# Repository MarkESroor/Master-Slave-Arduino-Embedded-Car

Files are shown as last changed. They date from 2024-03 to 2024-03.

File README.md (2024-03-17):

# Master Slave Arduino Embedded Car
 
The main idea is to implement a micro-controller based carwith multiple safety and entertainment features,
and apply the scheduling techniques that raise the safety level to a maximum.
It includes an autonomous lane departure system to avoid sway while moving and
keeping the driving path to avoid collision; it corrects the path with the right speed
while alerting the driver. In addition, the current gear of the car is displayed and can
be changed using a joystick. Moreover, adaptive headlights safety is not just limited
to the driver but to those around him as well. The headlights are adjusted
according to the brightness surrounding the car, meaning that at night the
headlights will work with enough intensity to show the road but not high enough to
obstruct the vision of other drivers. Finally, the sound system, user can play any
mp3 file through the touchscreen. The mp3 file name will be displayed and the user
can Play/Pause and iterate between the saved mp3 files.

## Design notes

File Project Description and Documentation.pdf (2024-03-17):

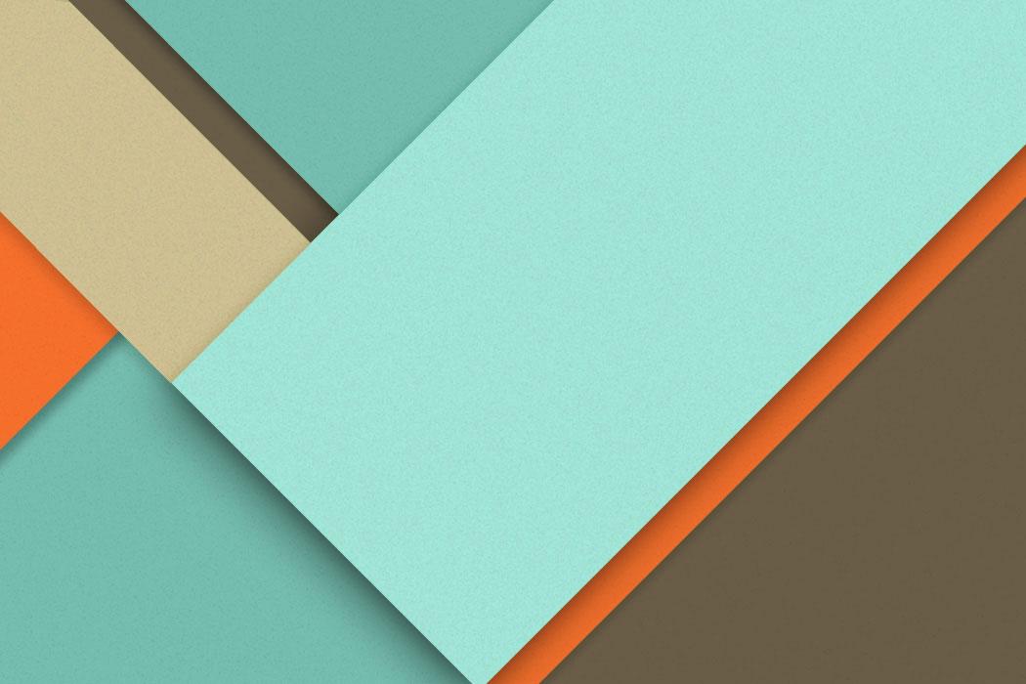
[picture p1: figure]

# Team 17

Name | ID | Tutorial Group
Mark Sroor | 46-5861 | T-22
Lougina Hatem | 46-13014 | T-22
Dareen Mohamed | 46-0416 | T-18
Omar Galal | 46-1097 | T-12

## Project Idea

The main idea is to implement a micro-controller based car with multiple safety and entertainment features .
and apply the scheduling techniques that raise the safety level to a maximum ,
It includes an autonomous lane departure system to avoid sway while moving and keeping the driving path to avoid collision; it corrects the path with the right speed while alerting the driver. In addition, the current gear of the car is displayed and can be changed using a joystick. Moreover, adaptive headlights safety is not just limited to the driver but to those around him as well. The headlights are adjusted according to the brightness surrounding the car, meaning that at night the headlights will work with enough intensity to show the road but not high enough to obstruct the vision of other drivers. Finally, the sound system, user can play any mp3 file through the touchscreen. The mp3 file name will be displayed and the user can Play/Pause and iterate between the saved mp3 files.

## Approach

First we worked on getting every component to be functional separately. Then we combined them together. After that we combined both arduinos and integrated everything.

C

i

r

c

u

i

t

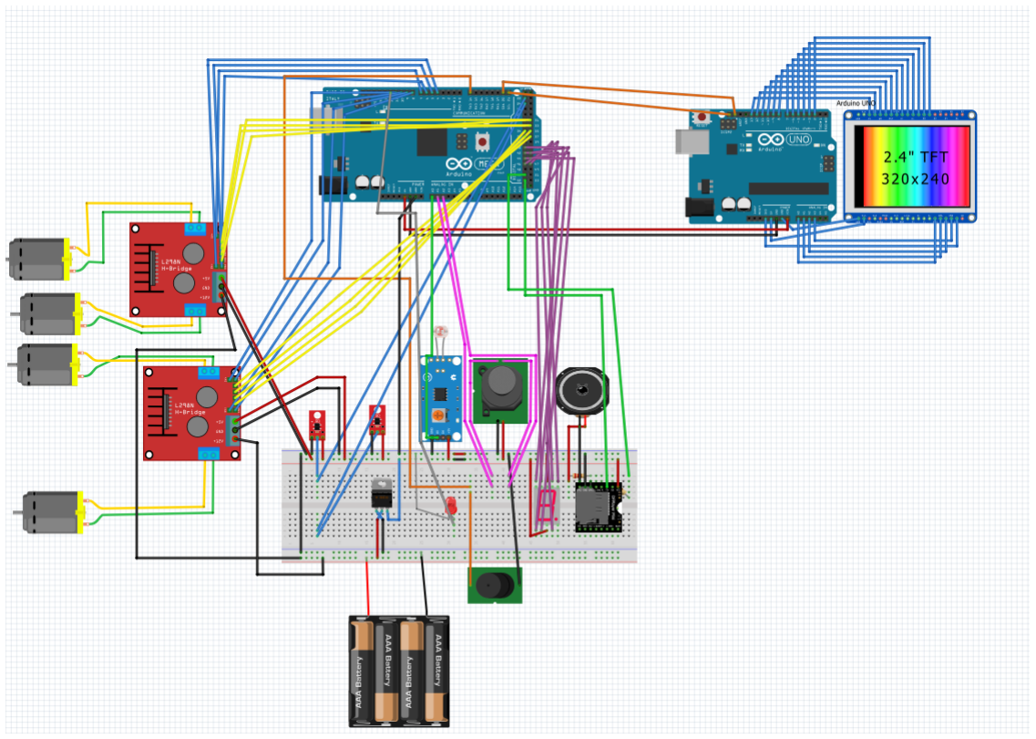
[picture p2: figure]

# Handling Inputs:

Regarding our inputs, they were from our sensors like our light detection sensor, lane detection sensor. These sensors were connected to the pwm ports of our arduino as we needed from analog to digital.

# Handling Outputs:

Regarding our outputs, they were from our sensors like our light detection sensor, lane detection sensor. These sensors were connected to the pwm ports of our arduino as we needed from analog to digital.

# Input and output pins and their configurations:

Arduino Mega Pins Input/Output:

- left (Left Lane Sensor), Pin =22, Type = analog input
- right (Right Lane Sensor), Pin = 24, Type analog input
●
- led1, Pin = 12, Type = digital output
Motor Pins
- const int IN1 = 30; //right back wheel Forward
- const int IN2 = 31; //right back wheel Reverse
- const int IN3 = 32; //right front wheel Forward
- const int IN4 = 33; //right front wheel Reverse
- //To turn motor on, off and control speed
- int en3 = 6; //enable for right back wheel pwm
- int en4 = 7; //enable for right back wheel pwm
- int en2 = 4; //enable for right front wheel pwm
- int en1 = 5; //enable for right front wheel pwm
●
- const int IN11 = 34; //left front wheel Forward
- const int IN22 = 35; //left front wheel Reverse
- const int IN33 = 36; //left back wheel Forward
- const int IN44 = 37; //left back wheel Reverse
- //To turn motor on, off and control speed
- int en33 = 11; // enable for left back wheel
- int en44 = 10; // enable for left back wheel

- int en22 = 9; // enable for left front wheel
- int en11 = 8; // enable for left front wheel
●

VRx (Gear Input Direction), Pin = A1, Type = analog input
VRy (Gear Input Direction), Pin = A2, Type = analog input
SW (Gear Input Direction of Parking), Pin = 53, Type = digital input a, Pin = 24, Type = digital output
3.5. Name = b, Pin = 22, Type = digital output
3.6. Name = c, Pin = 16, Type = digital output
3.7. Name = d, Pin = 15, Type = digital output
3.8. Name = e, Pin = 14, Type = digital output
3.9. Name = f, Pin = 19, Type = digital output
3.10. Name = g, Pin = 18, Type = digital output
3.11. Name = h, Pin = 17, Type = digital output

Arduino Uno Pins Input/Output:
1. Touch Screen Pins 1.1. Name = YP, Pin = A3, Type = analog input
1.2. Name = XM, Pin = A2, Type = analog input
1.3. Name = YM, Pin = 9, Type = digital input
1.4. Name = XP, Pin = 8, Type = digital input
1.5. Name = LCD_RD, Pin = A0, Type = analog input
1.6. Name = LCD_WR, Pin = A1, Type = analog input
1.7. Name = LCD_CD, Pin = A2, Type = analog input
1.8. Name = LCD_CS, Pin = A3, Type = analog input
1.9. Name = LCD_RESET, Pin = A4, Type = analog input

1.10. Name = LED_PIN, Pin = A5, Type = digital input

## Components Used

## I. 4WD Smart Robot Car Chassis Kit

We used the 4WD smart robot car chassis kit as the main support structure for our car. It comes with 4 DC gear motors.

## II. Arduino Shield “LCD TFT 2.4 With Touch Screen”

This touch screen acted as the graphical interface for the arduino. It was used to control the sound system of the car, such as pausing/playing a song, playing the previous/next song, and displaying the song name on the screen.

## III. 4pin Photoresistor, LDR Module – Optical Sensitive Resistance Light Detection Sensor Module

This sensor was used to detect light intensity.

## IV. MP3 Mini Player

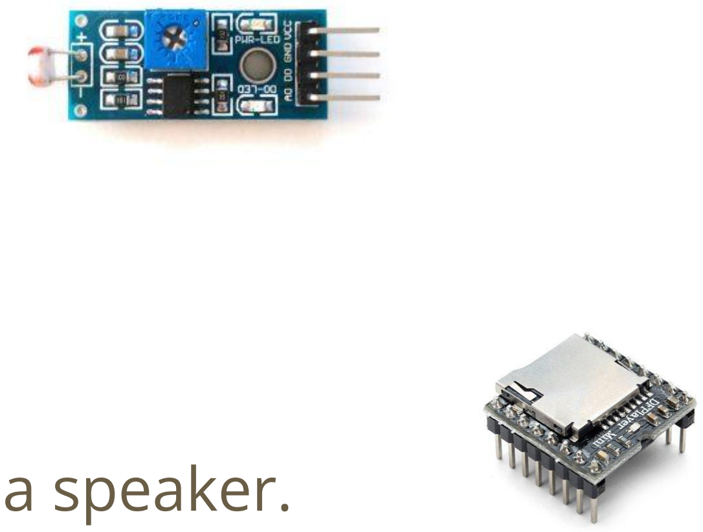
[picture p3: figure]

Songs were played using the MP3 mini player via a speaker.

## V. Breadboard

Used to connect the components

## VI. 7 Segment Display

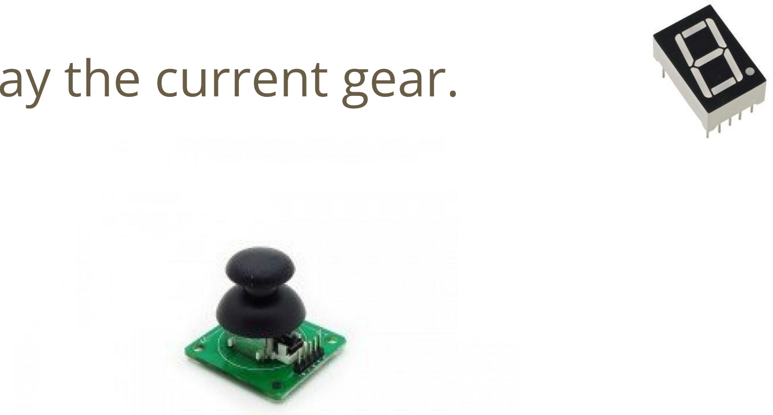
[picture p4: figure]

7 Segment display was used to display the current gear.

## VII. Joystick

A joystick was used to control the gear.

## VIII. QRE1113 Digital Line Tracker (Follower) Sensor

The Line tracker sensor was used to keep the car moving into its lane and detect if it’s leaving the lane.

## IX. Arduino Uno

## X. Arduino Mega

## XI. LED

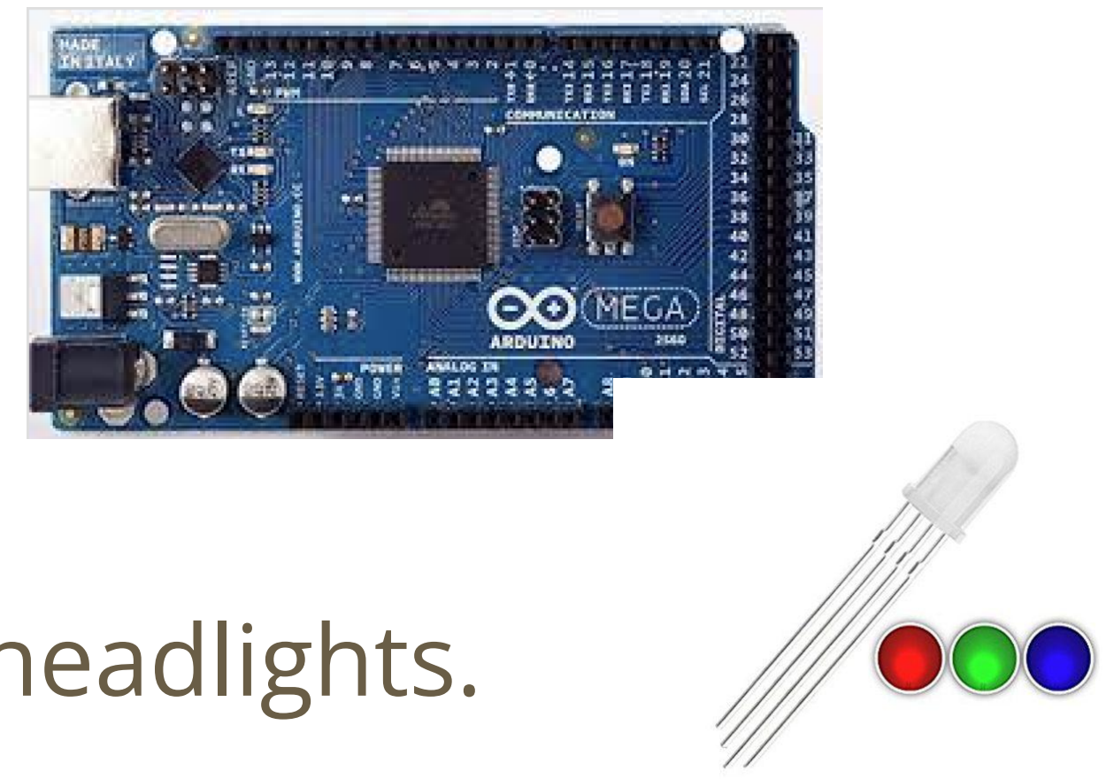
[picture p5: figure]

Used as the car headlights.

## Libraries

#include <Wire.h>

//This library allows you to communicate with I2C / TWI devices

// Functions:begin(),requestFrom(),beginTransmission(),endTransmission(),

write(),available(),read(),

#include <Arduino_FreeRTOS.h>

//This library provides the arduino with real time scheduling functionality, inter-task communication, timing and synchronization primitives and allows the use of these functions

//Functions:
xTaskCreate(),pdMS_TO_TICKS(),xTaskGetTickCount(),vTaskDelayUntil()

#include "SoftwareSerial.h"

//allow serial communication on digital pins of the Arduino other than pins 0 and 1, using software to replicate the functionality.

//Functions: begin(),write()

#include <Fonts/FreeSans9pt7b.h> #include <Fonts/FreeSans12pt7b.h> #include <FreeDefaultFonts.h>

#include <Adafruit_GFX.h>,#include <MCUFRIEND_kbv.h>

//graphics library used for all LCD displays providing a set of graphics functions //Functions:width(),height(),readID(),begin(), fillScreen(),drawFastHLine(),setFont(),setCursor(),setTextColor(), setTextSize(),print(),fillRect()

#include <TouchScreen.h>

//Functions:getPoint(),

# Handling Inputs:

Regarding our inputs, they were from our sensors like our slim

# FreeRTOS:

Features were divided upon Arduino Uno (master) and Arduino Mega (Slave). Where Arduino Uno was assigned the screen only and the remaining features & functionalities were assigned to the Arduino Mega. The Lane Keeping Assist’s feature was given the highest priority (3 but not the only task with this priority) and had a delay of only 100ms.

## Lane Keeping Assist (LKA) :

- Controlling the motors’ speed ,motors’ movement and line sensor were all handled in a periodic task with a priority of 3 and a mere delay of 100ms to prevent starvation of the other tasks.

## Control Indicators (CI) :

- Controlling the joystick was put into a task in the Mega that reads the input and sets the 7-Segment Display according to the current gear with priority of 2 and a periodic delay of 1000ms.
- Light intensity control was assigned a task of priority 2 and periodic delay of 750ms which sets the LED according to the light intensity being read.

## Sound System (SS) :

- Getting input from the touchscreen and sending output to the slave were handled in the Uno without the use of tasks as there was only one functionality in the Uno. Manipulating the input in the slave was not put in a task.
- Sending the song that is currently being played to the master was put in a task in the Mega with priority equal to 3 with a periodic delay of 1500ms.

# Limitations :

A number of limitations and setbacks were faced during the implementation of the project that were later overcome after testing and researching.

- Playing songs from the MP3 module in a timely manner when the LCD gets an input was challenging because of the delays from the I2C , tasks priorities and the fact that the MP3 module repeatedly disconnects.
- Light sensitivity of the LDR was not very accurate.
- Speaker gets burned frequently whenever a flow of high voltage occurs.
- FreeRTOS and giving the tasks different priorities to ensure that no starvation or deadlocks occur to any of the tasks.
- Communication between Arduino Uno (master) and Arduino Mega (slave) using I2C.
- Line Sensor needed to be lined very closely to the lane that was being followed ,which should not be reflective to avoid inaccurate results.

# Work Division :

All team members worked collectively on all parts to deliver the

requirements and all features were implemented by all members together with no feature assigned exclusively to any member.

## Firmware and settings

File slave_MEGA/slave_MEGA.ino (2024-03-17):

///              MP3 PLAYER PROJECT
/// http://educ8s.tv/arduino-mp3-player/
//////////////////////////////////////////
#include <Wire.h>
#include <Arduino_FreeRTOS.h>
#include <semphr.h>
#include "SoftwareSerial.h"
void receiveEvent(int howMany);
void bcd(int selector);
void playFirst();
void requestEvent();
int buzzer = 14; 
SoftwareSerial mySerial(52, 50);
# define Start_Byte 0x7E
# define Version_Byte 0xFF
# define Command_Length 0x06
# define End_Byte 0xEF
# define Acknowledge 0x00 //Returns info with command 0x41 [0x01: info, 0x00: no info]
const int A = 46;
const int B = 47;
const int C = 42;
const int D = 44;
const int E = 45;
const int F = 43;
const int G = 40;

const int IN1 = 30; //right back wheel Forward
const int IN2 = 31; //right back wheel  Reverse
const int IN3 = 32; //right front wheel  Forward
const int IN4 = 33; //right front wheel  Reverse
//To turn motor on, off and control speed
int en3 = 6; //enable for right back wheel pwm
int en4 = 7; //enable for right back wheel pwm
int en2 = 4; //enable for right front wheel  pwm
int en1 = 5; //enable for right front wheel  pwm

const int IN11 = 34; //left front wheel Forward
const int IN22 = 35; //left front wheel Reverse
const int IN33 = 36; //left back wheel Forward
const int IN44 = 37; //left back wheel Reverse
//To turn motor on, off and control speed
int en33 = 11;  // enable for left back wheel
int en44 = 10;  // enable for left back wheel
int en22 = 9;   // enable for left front wheel
int en11 = 8;   // enable for left front wheel

int QRE1113_Pin = 22; //connected to digital 1
int QRE1114_Pin = 24; //connected to digital 2

boolean dfPlayerStarted = false;
int songNumber = 0;
//task definitions:

void ldr ( void *pvParameters);
void readFromScreen ( void *pvParameters);


# define ACTIVATED LOW


boolean isPlaying = false;
//#if 1


#include "DFRobotDFPlayerMini.h"
DFRobotDFPlayerMini myDFPlayer;
SemaphoreHandle_t Mutex;
int currGear = 1;
int prevGear = 0;
void setup () {
  pinMode(A2, INPUT); //x
  pinMode(A1, INPUT); //y
  // pinMode( ,INPUT);

  pinMode(A, OUTPUT);
  pinMode(B, OUTPUT);
  pinMode(C, OUTPUT);
  pinMode(D, OUTPUT);
  pinMode(E, OUTPUT);
  pinMode(F, OUTPUT);
  pinMode(G, OUTPUT);
   pinMode(buzzer, OUTPUT);

  pinMode (IN1, OUTPUT);
  pinMode (IN2, OUTPUT);
  pinMode (IN3, OUTPUT);
  pinMode (IN4, OUTPUT);
  pinMode (en1, OUTPUT);
  pinMode (en2, OUTPUT);
  pinMode (en3, OUTPUT);
  pinMode (en4, OUTPUT);

  pinMode (IN11, OUTPUT);
  pinMode (IN22, OUTPUT);
  pinMode (IN33, OUTPUT);
  pinMode (IN44, OUTPUT);
  pinMode (en11, OUTPUT);
  pinMode (en22, OUTPUT);
  pinMode (en33, OUTPUT);
  pinMode (en44, OUTPUT);

  Serial.begin(115200);
  mySerial.begin(9600);
  Wire.begin(4);
  Wire.onReceive(receiveEvent);
  Wire.onRequest(requestEvent);
  // pinMode(A6,INPUT);
  //  pinMode(A5,OUTPUT);
  if (!myDFPlayer.begin(mySerial)) {  //Use softwareSerial to communicate with mp3.
    Serial.println(F("Unable to begin:"));
    Serial.println(F("1.Please recheck the connection!"));
    Serial.println(F("2.Please insert the SD card!"));
    //while(true);
  }
  delay(1000);
  dfPlayerStarted= true;
  playFirst();
  isPlaying = true;
  Mutex = xSemaphoreCreateMutex();

  xTaskCreate(ldr, "ldr", 500, NULL, 2, NULL);
  xTaskCreate(joystick, "joystick", 500, NULL, 2, NULL);
  xTaskCreate(motor,"motor",500,NULL,3,NULL);
  xTaskCreate(getSong,"getSong",500,NULL,3,NULL);
}
void getSong ( void *pvParameters) {
    TickType_t joyStickWakeTime;
  const TickType_t joyStickDelay = pdMS_TO_TICKS(1500);
  joyStickWakeTime = xTaskGetTickCount();
while(1){
  songNumber = myDFPlayer.readCurrentFileNumber();
   vTaskDelayUntil(&joyStickWakeTime , joyStickDelay);
}
}
void joystick ( void *pvParameters) {
  TickType_t joyStickWakeTime;
  const TickType_t joyStickDelay = pdMS_TO_TICKS(1000);
  joyStickWakeTime = xTaskGetTickCount();
  while (1) {
//    Serial.println("JOYSTICK");
    int x = analogRead(A2);
    int y = analogRead(A1); //assign value of LDR sensor to a temporary variable
//    Serial.print("X"); Serial.println(x);
//    Serial.print("Y"); Serial.println(y);
    if (y > 800)
      bcd(1);
    else if (y < 300)
      bcd(3);
    else if (x < 300)
      bcd(2);
    else if (x > 800)
      bcd(4);
    //xSemaphoreGive(Mutex);
    vTaskDelayUntil(&joyStickWakeTime , joyStickDelay);
  }
}
void ldr ( void *pvParameters) {
  TickType_t ldrWakeTime;
  const TickType_t ldrDelay = pdMS_TO_TICKS(750);
  ldrWakeTime = xTaskGetTickCount();
  while (1) {
    //Serial.println("ldr");
    //xSemaphoreTake(Mutex, portMAX_DELAY);
    int temp = analogRead(A0); //input ldr pin      //assign value of LDR sensor to a temporary variable
    //  Serial.println("Intensity="); //print on serial monitor using ""
    //  Serial.println(temp);         //display output on serial monitor
    //HIGH means,light got blocked
    analogWrite(12, temp / 4); //pin 12 for led        //if light is not present,LED on
    //xSemaphoreGive(Mutex);
    vTaskDelayUntil(&ldrWakeTime , ldrDelay);

  }
}

void motor( void *pvParameters) {
  TickType_t motorLastWakeTime;
  const TickType_t motorDelay = pdMS_TO_TICKS(100);
  motorLastWakeTime = xTaskGetTickCount();
  while (1) {
   // Serial.println("motor");
    //control speed

    int QRE_Value2 = readQD();//left line follower
     Serial.println("value2");
      Serial.println(QRE_Value2);
    if (QRE_Value2 >
    2999) { //left line follower detected line so we need to steer to the right, dec pwm on left wheels
     
      analogWrite(en1, 255);
      analogWrite(en2, 255);
      analogWrite(en3, 255);
      analogWrite(en4, 255);
      //Serial.println(en1);

      //control direction
     digitalWrite(IN1, HIGH);
    digitalWrite(IN2, LOW);
    digitalWrite(IN3, HIGH);
    digitalWrite(IN4, LOW);

      //control speed REVERSE HERE
      analogWrite(en11, 255);
      analogWrite(en22, 255);
      analogWrite(en33, 255);
      analogWrite(en44, 255);
      //control direction
    digitalWrite(IN11, LOW);
    digitalWrite(IN22, HIGH);
    digitalWrite(IN33, HIGH);
    digitalWrite(IN44, LOW);
      // delay(500);
      digitalWrite(buzzer, HIGH);
    }


    int QRE_Value = readQD2();
    //Serial.println(QRE_Value);
      Serial.println("value1");
      Serial.println(QRE_Value);
    if (QRE_Value >2999) { //right line follower detected line so we need to steer to the left, dec pwm on right wheels
   //REVERSE
      analogWrite(en1, 255);
      analogWrite(en2, 255);
      analogWrite(en3, 255);
      analogWrite(en4, 255);
      //control direction
  digitalWrite(IN1, LOW);
    digitalWrite(IN2, HIGH);
    digitalWrite(IN3, LOW);
    digitalWrite(IN4, HIGH);

      //control speed
      analogWrite(en11, 255);
      analogWrite(en22, 255);
      analogWrite(en33, 255);
      analogWrite(en44, 255);
      //control direction
  digitalWrite(IN11, HIGH);
    digitalWrite(IN22, LOW);
    digitalWrite(IN33, LOW);
    digitalWrite(IN44, HIGH);
      //delay(500);
digitalWrite(buzzer, HIGH);
    }





if(QRE_Value <=2999 &&QRE_Value2 <=2999){
  digitalWrite(buzzer, LOW);
    analogWrite(en1, 180);
    analogWrite(en2, 180);
    analogWrite(en3, 180);
    analogWrite(en4, 180);
    //control direction
    digitalWrite(IN1, HIGH);
    digitalWrite(IN2, LOW);
    digitalWrite(IN3, HIGH);
    digitalWrite(IN4, LOW);

    //control speed
    analogWrite(en11, 180);
    analogWrite(en22, 180);
    analogWrite(en33, 180);
    analogWrite(en44, 180);
    //control direction
    digitalWrite(IN11, HIGH);
    digitalWrite(IN22, LOW);
    digitalWrite(IN33, LOW);
    digitalWrite(IN44, HIGH);
}
    vTaskDelayUntil(&motorLastWakeTime , motorDelay);
  }
}


int readQD(){
//Returns value from the QRE1113
//Lower numbers mean more refleacive
//More than 3000 means nothing was reflected.
pinMode( QRE1113_Pin, OUTPUT );
digitalWrite( QRE1113_Pin, HIGH );
delayMicroseconds(10);
pinMode( QRE1113_Pin, INPUT );

long time = micros();

//time how long the input is HIGH, but quit after 3ms as nothing happens after that
while (digitalRead(QRE1113_Pin) == HIGH && micros() - time < 3000); 
int diff = micros() - time; return diff; }

void requestEvent() {
   if (dfPlayerStarted) {  //Use softwareSerial to communicate with mp3.
    //  Serial.println("dfplayer shaghal");
      Wire.write(songNumber);

       
//  int songNumber = 1;
// Wire.write(songNumber);
  }else{
     // Serial.println("dfplayer mesh shaghal");
      Wire.write(-1);
}
//Serial.println("on request");
  //int songNumber = myDFPlayer.readCurrentFileNumber();

  
  //Serial.println(songNumber);
}
int readQD2(){
//Returns value from the QRE1113
//Lower numbers mean more refleacive
//More than 3000 means nothing was reflected.
pinMode( QRE1114_Pin, OUTPUT );
digitalWrite( QRE1114_Pin, HIGH );
delayMicroseconds(10);
pinMode( QRE1114_Pin, INPUT );

long time = micros();

//time how long the input is HIGH, but quit after 3ms as nothing happens after that
while (digitalRead(QRE1114_Pin) == HIGH && micros() - time < 3000); 
int diff = micros() - time; return diff; }

void receiveEvent(int howMany)
{

  int x = Wire.read();    // receive byte as an integer
  //Serial.println(x);         // print the integer
  switch (x) {
    case 0:{
      // statements
      isPlaying=false;
      pause();}
      break;
    case 1:{
      // statements
      play();
      isPlaying=true;
    }
      break;
    case 2:
      // statements
      if(isPlaying){
      playNext();
      }
      break;
    case 3:
      // statements
      if(isPlaying){
      playPrevious();}
      break;
    default:
      // statements
      break;
  }
}

String curr = "";
void loop () {

}

void playFirst()
{
  execute_CMD(0x3F, 0, 0);
  //  delay(500);
//  setVolume(30);
  //  delay(500);
  execute_CMD(0x11, 0, 1);
  delay(500);
}

void pause()
{
  execute_CMD(0x0E, 0, 0);
//  delay(500);
}

void play()
{
  execute_CMD(0x0D, 0, 1);
//  setVolume(30);
//  delay(500);
}

void playNext()
{
  execute_CMD(0x01, 0, 1);
//  setVolume(30);
//  delay(500);
}

void playPrevious()
{
  execute_CMD(0x02, 0, 1);
//  delay(500);
}

void setVolume(int volume)
{
  execute_CMD(0x06, 0, volume); // Set the volume (0x00~0x30)
//  delay(2000);
}

void execute_CMD(byte CMD, byte Par1, byte Par2)
// Excecute the command and parameters
{
  // Calculate the checksum (2 bytes)
  word checksum = -(Version_Byte + Command_Length + CMD + Acknowledge + Par1 + Par2);
  // Build the command line
  byte Command_line[10] = { Start_Byte, Version_Byte, Command_Length, CMD, Acknowledge,
                            Par1, Par2, highByte(checksum), lowByte(checksum), End_Byte
                          };
  //Send the command line to the module
  for (byte k = 0; k < 10; k++)
  {
    mySerial.write( Command_line[k]);
  }
}

void bcd(int selector) {
  if (selector == 1 ) {
    currGear = 1;
    digitalWrite(A, HIGH);
    digitalWrite(D, HIGH);
    digitalWrite(E, HIGH);
    digitalWrite(F, HIGH);
    digitalWrite(G, HIGH);
    digitalWrite(B, LOW);
    digitalWrite(C, LOW);
  }
  else if (selector == 2) {
    currGear = 2;
    digitalWrite(A, LOW);
    digitalWrite(B, LOW);
    digitalWrite(C, HIGH);
    digitalWrite(G, LOW);
    digitalWrite(F, HIGH);
    digitalWrite(E, LOW);
    digitalWrite(D, LOW);
  }
  else if (selector == 3) {
    currGear = 3;
    digitalWrite(A, LOW);
    digitalWrite(B, LOW);
    digitalWrite(C, LOW);
    digitalWrite(D, LOW);
    digitalWrite(E, HIGH);
    digitalWrite(F, HIGH);
    digitalWrite(G, LOW);
  }
  else if (selector == 4) {
    currGear = 4;
    digitalWrite(F, LOW);
    digitalWrite(G, LOW);
    digitalWrite(B, LOW);
    digitalWrite(C, LOW);
    digitalWrite(A, HIGH);
    digitalWrite(D, HIGH);
    digitalWrite(E, HIGH);

  }
}

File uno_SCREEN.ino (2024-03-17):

// Wire Master Writer
// by Nicholas Zambetti <http://www.zambetti.com>

// Demonstrates use of the Wire library
// Writes data to an I2C/TWI slave device
// Refer to the "Wire Slave Receiver" example for use with this

// Created 29 March 2006

#include <Arduino.h>
#include <Arduino_FreeRTOS.h>
#include <semphr.h>
# define Start_Byte 0x7E
# define Version_Byte 0xFF
# define Command_Length 0x06
# define End_Byte 0xEF
# define Acknowledge 0x00 //Returns info with command 0x41 [0x01: info, 0x00: no info]
void general ( void *pvParameters);
#include <Wire.h>

#include <Adafruit_GFX.h>
#include <MCUFRIEND_kbv.h>
MCUFRIEND_kbv tft;
#include <TouchScreen.h>
#define MINPRESSURE 200
#define MAXPRESSURE 1000

#include <Fonts/FreeSans9pt7b.h>
#include <Fonts/FreeSans12pt7b.h>
#include <Fonts/FreeSerif12pt7b.h>

#include <FreeDefaultFonts.h>
# define ACTIVATED LOW
#define BLACK   0x0000
#define BLUE    0x001F
#define RED     0xF800
#define GREEN   0x07E0
#define CYAN    0x07FF
#define MAGENTA 0xF81F
#define YELLOW  0xFFE0
#define WHITE   0xFFFF
char* songName="";
boolean isPlaying = false;
// ALL Touch panels and wiring is DIFFERENT
// copy-paste results from TouchScreen_Calibr_native.ino
const int XP = 8, XM = A2, YP = A3, YM = 9; //ID=0x9341
const int TS_LEFT = 135, TS_RT = 884, TS_TOP = 100, TS_BOT = 890;
TouchScreen ts = TouchScreen(XP, YP, XM, YM, 300);

void lcd( void *pvParameters);
SemaphoreHandle_t xSemaphore;

Adafruit_GFX_Button on_btn, off_btn, on_btn2, off_btn2;

int pixel_x, pixel_y;     //Touch_getXY() updates global vars
bool Touch_getXY(void)
{
  TSPoint p = ts.getPoint();
  pinMode(YP, OUTPUT);      //restore shared pins
  pinMode(XM, OUTPUT);
  digitalWrite(YP, HIGH);   //because TFT control pins
  digitalWrite(XM, HIGH);
  bool pressed = (p.z > MINPRESSURE && p.z < MAXPRESSURE);
  if (pressed) {
    pixel_x = map(p.x, TS_LEFT, TS_RT, 0, tft.width()); //.kbv makes sense to me
    pixel_y = map(p.y, TS_TOP, TS_BOT, 0, tft.height());
  }
  return pressed;
}


void setup()
{
  Wire.begin(); // join i2c bus (address optional for master)

  Serial.begin(9600);

  uint16_t ID = tft.readID();
  Serial.print("TFT ID = 0x");
  Serial.println(ID, HEX);
  showmsgXY(20, 60, 1, &FreeSans9pt7b, "FreeSans9pt7b");
  Serial.println("Calibrate for your Touch Panel");
  if (ID == 0xD3D3) ID = 0x9486; // write-only shield
  tft.begin(ID);
  //    tft.setRotation(2);            //PORTRAIT
  tft.fillScreen(BLACK);
  on_btn.initButton(&tft,  60, 200, 100, 40, WHITE, CYAN, BLACK, "Pause", 1);
  on_btn2.initButton(&tft,  60, 250, 100, 40, WHITE, CYAN, BLACK, "Play", 1);
  off_btn.initButton(&tft, 180, 200, 100, 40, WHITE, CYAN, BLACK, "Next", 1);
  off_btn2.initButton(&tft, 180, 250, 100, 40, WHITE, CYAN, BLACK, "Previous", 1);
  on_btn.drawButton(false);
  on_btn2.drawButton(false);
  off_btn.drawButton(false);
  off_btn2.drawButton(false);
 // tft.fillRect(40, 80, 160, 80, RED);
  //xTaskCreate(lcd, "lcd", 2000, NULL, 2, NULL);0xffff 
  //xTaskCreate(songNumber, "songNumber", 2000, NULL, 3, NULL);
  Serial.println("before");
  //Serial.println(xTaskCreate(general, "general", 1500, NULL, 3, NULL));
  Serial.println("after");
}
int currSong = 0;
int prevSong = 0;


byte x = 0;

void general ( void *pvParameters) {
  Serial.println("before loop");
while(1){
 
}
}

void showmsgXY(int x, int y, int sz, const GFXfont *f, const char *msg)
{
  int16_t x1, y1;
  uint16_t wid, ht;
  tft.drawFastHLine(0, y, tft.width(), WHITE);
  tft.setFont(f);
  tft.setCursor(x, y);
  tft.setTextColor(WHITE);
  tft.setTextSize(sz);
  tft.print(msg);

}
void loop()
{
 //Serial.println("hi");
  Wire.beginTransmission(4); // transmit to device #4
    bool down = Touch_getXY();
    on_btn.press(down && on_btn.contains(pixel_x, pixel_y));
    off_btn.press(down && off_btn.contains(pixel_x, pixel_y));
    if (on_btn.justReleased())
      on_btn.drawButton(false);
    if (off_btn.justReleased())
      off_btn.drawButton(false);
    if (on_btn.justPressed()) {
      on_btn.drawButton(true);
        Wire.write(0); //pause
        Serial.println("0");

      }
    
    if (off_btn.justPressed()) {
      off_btn.drawButton(true);
    //  tft.fillRect(40, 80, 160, 80, RED);
      //if (isPlaying)
      //{
        Wire.write(2); //playNext
         Serial.println("2");
      //}
    }

    on_btn2.press(down && on_btn2.contains(pixel_x, pixel_y));
    off_btn2.press(down && off_btn2.contains(pixel_x, pixel_y));
    if (on_btn2.justReleased())
      on_btn2.drawButton(false);
    if (off_btn2.justReleased())
      off_btn2.drawButton(false);
    if (on_btn2.justPressed()) {
      on_btn2.drawButton(true);
          Wire.write(1); //play
         Serial.println("1");
      //tft.fillRect(40, 80, 160, 80, GREEN);
    }
    if (off_btn2.justPressed()) {
      off_btn2.drawButton(true);
      //tft.fillRect(40, 80, 160, 80, RED);
      //if (isPlaying)
      //{
        Wire.write(3); //playPrev
      //}
    }
    
    showmsgXY(20, 60, 1, &FreeSans9pt7b, songName);
      
    //
    //vTaskDelayUntil(&lcdWake , lcdDelay);
    Wire.requestFrom(4, 1);
    while (Wire.available()) {
      //Serial.print("read value ");
      currSong = Wire.read();
      //Serial.println(currSong);
      break;
    }
     Wire.endTransmission(); 
//
switch (currSong) {
  case (-1):
    songName = "Waiting for mp3 player";
    
    break;
  case 1:
    songName = "Wonderful World";
    break;
  case 2:
    // statements
     songName = "Sunflower";
    break;
      case 3:
    // statements
     songName = "Memories";
    break;
      case 4:
    // statements
     songName = "Rather Be";
    break;
      case 5:
    // statements
     songName = "Stand By Me";
    break;
  default:
    // statements
    songName = "Waiting";
    break;
}
  if(currSong!= prevSong){
    tft.fillRect(10, 40, 200, 30, BLACK);
  }

    prevSong=currSong;
 
}
